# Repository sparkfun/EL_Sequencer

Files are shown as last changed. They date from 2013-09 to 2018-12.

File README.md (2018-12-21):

EL Sequencer
============

[EL Sequencer  
*EL Sequencer (COM-11323)*](https://www.sparkfun.com/products/11323)

The EL Sequencer is a board that contains an Arduino-compatible microcontroller, 
and circuitry for controlling up to eight strands of electroluminescent wire.

Repository Contents
-------------------
* **/Firmware** - Example Arduino sketches
* **/Hardware** - All Eagle design files (.brd, .sch)

Documentation
--------------
* **[Getting Started with Electroluminescent (EL) Wire](https://learn.sparkfun.com/tutorials/getting-started-with--el-wire)** - Basic tutorial on EL Wire
* **[Hookup Guide](https://learn.sparkfun.com/tutorials/el-sequencerescudo-dos-hookup-guide)** - Basic hookup guide for the EL Sequencer

License Information
-------------------
The hardware is released under [Creative Commons Share-alike 3.0](http://creativecommons.org/licenses/by-sa/3.0/).  
All other code is open source so please feel free to do anything you want with it; 
you buy me a beer if you use this and we meet someday ([Beerware license](http://en.wikipedia.org/wiki/Beerware)).

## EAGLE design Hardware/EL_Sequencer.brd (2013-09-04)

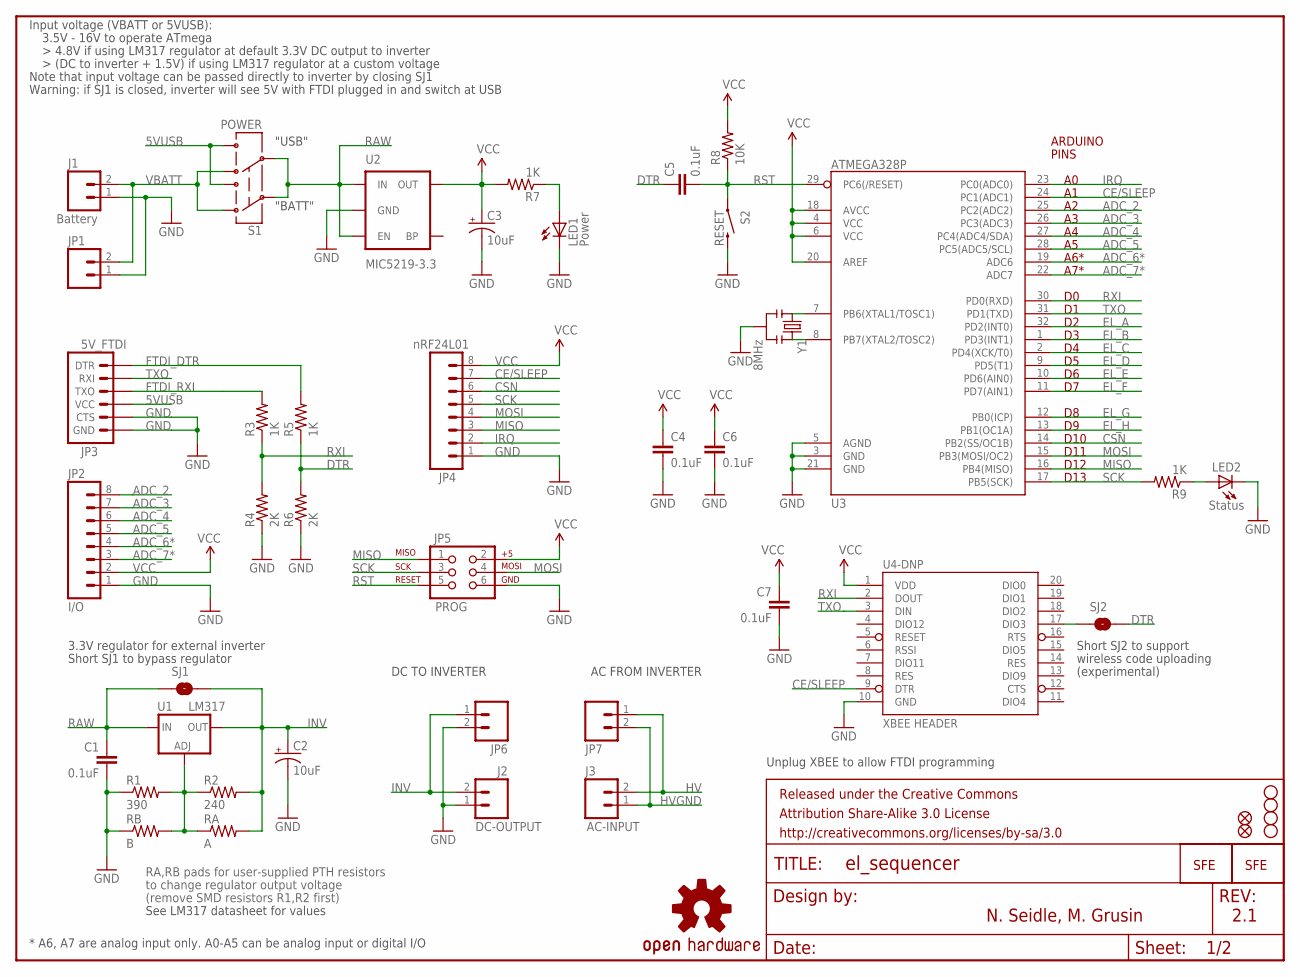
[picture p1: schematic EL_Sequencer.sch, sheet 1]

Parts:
C1, C4, C5, C6, C7: 0.1uF; 0402-CAP
C2, C3: 10uF; EIA3216
FRAME1: FRAME-LETTER; CREATIVE_COMMONS
J1: Battery; JST-2-SMD
J2: DC-OUTPUT; JST-2-SMD
J3: AC-INPUT; JST-2-SMD
JP1, JP6, JP7: M02PTH; 1X02
JP2: I/O; 1X08_ROUND
JP3: 5V_FTDI; 1X06
JP4: nRF24L01; 1X08
JP5: PROG; 2X3
JP8: LOGO-SFESK; SFE-LOGO-FLAME
LED1: Power; LED-0603
LED2: Status; LED-0603
R1: 390; 0603-RES
R2: 240; 0603-RES
R3, R5, R7, R9: 1K; 0402-RES
R4, R6: 2K; 0402-RES
R8: 10K; 0402-RES
RA: A; AXIAL-0.4
RB: B; AXIAL-0.4
S1: POWER; AYZ0202
S2: RESET; TACTILE_SWITCH_SMD
SJ1: SOLDERJUMPERROUND; SJ_ROUND
SJ2: SOLDERJUMPERNO; SJ_2S-NO
U1: LM317; V-REG_DPACK
U2: MIC5219-3.3; SOT23-5
U3: ATMEGA328P; TQFP32-08
U4-DNP: XBEE HEADER; XBEE-LONGPAD
U$1: OSHW-LOGOS; OSHW-LOGO-S
U$2: LOGO-SFENEW; SFE-NEW-WEBLOGO
U$3, U$4: FIDUCIALUFIDUCIAL; MICRO-FIDUCIAL
U$5, U$6, U$7, U$8: STAND-OFF
Y1: 8MHz; RESONATOR-SMD

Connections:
5VUSB: JP3.4 (VCC), S1.3, S1.6
ADC_2: JP2.8, U3.25 (PC2(ADC2))
ADC_3: JP2.7, U3.26 (PC3(ADC3))
ADC_4: JP2.6, U3.27 (PC4(ADC4/SDA))
ADC_5: JP2.5, U3.28 (PC5(ADC5/SCL))
ADC_6*: JP2.4, U3.19 (ADC6)
ADC_7*: JP2.3, U3.22 (ADC7)
CE/SLEEP: JP4.7, U3.24 (PC1(ADC1)), U4-DNP.9 (DTR)
CSN: JP4.6, U3.14 (PB2(SS/OC1B))
DTR: C5.1, R5.1, R6.2, SJ2.2
EL_A: U3.32 (PD2(INT0)); also elsewhere on the board
EL_B: U3.1 (PD3(INT1)); also elsewhere on the board
EL_C: U3.2 (PD4(XCK/T0)); also elsewhere on the board
EL_D: U3.9 (PD5(T1)); also elsewhere on the board
EL_E: U3.10 (PD6(AIN0)); also elsewhere on the board
EL_F: U3.11 (PD7(AIN1)); also elsewhere on the board
EL_G: U3.12 (PB0(ICP)); also elsewhere on the board
EL_H: U3.13 (PB1(OC1A)); also elsewhere on the board
FTDI_DTR: JP3.1 (DTR), R5.2
FTDI_RXI: JP3.3 (TXO), R3.2
GND: C1.2, C2.C (-), C3.C (-), C4.2, C6.2, C7.2, J1.1, J2.1, JP1.1, JP2.1, JP3.5 (CTS), JP3.6 (GND), JP4.1, JP5.6, JP6.2, LED1.C, LED2.C, R1.1, R4.1, R6.1, RB.P$1 (1), S2.3 (2), U2.2 (GND), U3.3 (GND), U3.5 (AGND), U3.21 (GND), U4-DNP.10 (GND), Y1.2; also elsewhere on the board
HV: J3.2, JP7.1; also elsewhere on the board
HVGND: J3.1, JP7.2; also elsewhere on the board
INV: C2.A (+), J2.2, JP6.1, R2.2, RA.P$2 (2), SJ1.2, U1.4 (OUT)
IRQ: JP4.2, U3.23 (PC0(ADC0))
MISO: JP4.3, JP5.1, U3.16 (PB4(MISO))
MOSI: JP4.4, JP5.4, U3.15 (PB3(MOSI/OC2))
unnamed: U3.7 (PB6(XTAL1/TOSC1)), Y1.1
unnamed: LED1.A, R7.1
unnamed: U3.8 (PB7(XTAL2/TOSC2)), Y1.3
unnamed: SJ2.1, U4-DNP.17 (DIO3)
unnamed: R1.2, R2.1, RA.P$1 (1), RB.P$2 (2), U1.1 (ADJ)
unnamed: LED2.A, R9.1
RAW: C1.1, S1.2, S1.5, SJ1.1, U1.3 (IN), U2.1 (IN), U2.3 (EN)
RST: C5.2, JP5.5, R8.1, S2.1, U3.29 (PC6(/RESET))
RXI: R3.1, R4.2, U3.30 (PD0(RXD)), U4-DNP.2 (DOUT)
SCK: JP4.5, JP5.3, R9.2, U3.17 (PB5(SCK))
TXO: JP3.2 (RXI), U3.31 (PD1(TXD)), U4-DNP.3 (DIN)
VBATT: J1.2, JP1.2, S1.1, S1.4
VCC: C3.A (+), C4.1, C6.1, C7.1, JP2.2, JP4.8, JP5.2, R7.2, R8.2, U2.5 (OUT), U3.4 (VCC), U3.6 (VCC), U3.18 (AVCC), U3.20 (AREF), U4-DNP.1 (VDD)

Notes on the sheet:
DC TO INVERTER
RA,RB pads for user-supplied PTH resistors
to change regulator output voltage
(remove SMD resistors R1,R2 first)
AC FROM INVERTER
A6*
A7*
D10
D11
D12
D13
N. Seidle, M. Grusin
2.1
Short SJ1 to bypass regulator
3.3V regulator for external inverter
Short SJ2 to support
wireless code uploading
* A6, A7 are analog input only. A0-A5 can be analog input or digital I/O
ARDUINO
PINS
See LM317 datasheet for values
(experimental)
3.5V - 16V to operate ATmega
Input voltage (VBATT or 5VUSB):
Note that input voltage can be passed directly to inverter by closing SJ1
Warning: if SJ1 is closed, inverter will see 5V with FTDI plugged in and switch at USB
"USB"
"BATT"
Unplug XBEE to allow FTDI programming

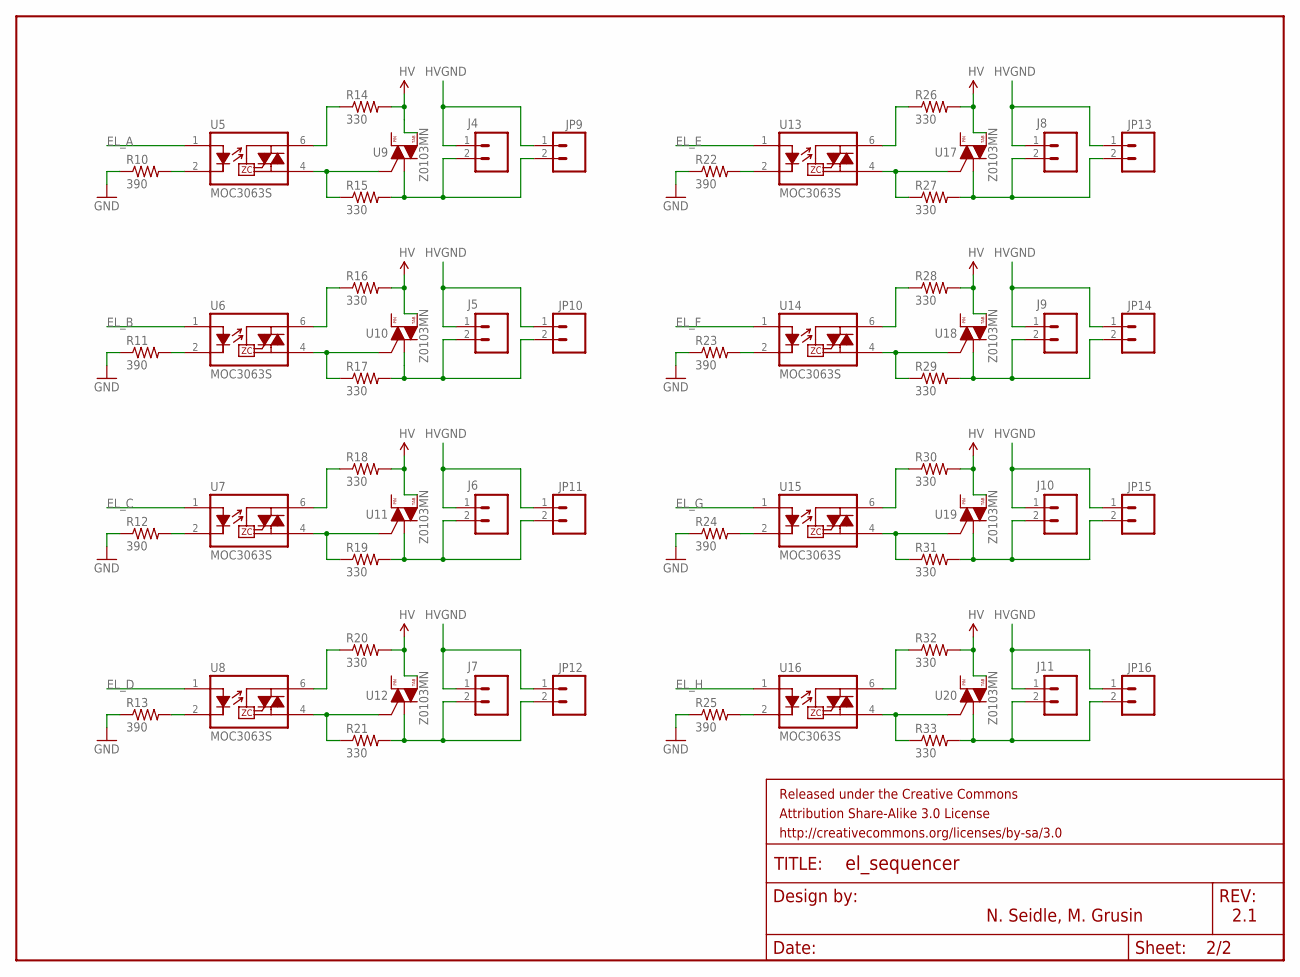
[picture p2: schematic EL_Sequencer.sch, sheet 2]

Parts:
FRAME2: FRAME-LETTER; CREATIVE_COMMONS
J4, J5, J6, J7, J8, J9, J10, J11: M02-JST-2MM-SMT; JST-2-SMD
JP9, JP10, JP11, JP12, JP13, JP14, JP15, JP16: M02PTH; 1X02
R10, R11, R12, R13, R22, R23, R24, R25: 390; 0402-RES
R14, R15, R16, R17, R18, R19, R20, R21, R26, R27, R28, R29, R30, R31, R32, R33: 330; 0603-RES
U5, U6, U7, U8, U13, U14, U15, U16: MOC3063S; DIP8SMD
U9, U10, U11, U12, U17, U18, U19, U20: Z0103MN; SOT223

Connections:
EL_A: U5.1 (A); also elsewhere on the board
EL_B: U6.1 (A); also elsewhere on the board
EL_C: U7.1 (A); also elsewhere on the board
EL_D: U8.1 (A); also elsewhere on the board
EL_E: U13.1 (A); also elsewhere on the board
EL_F: U14.1 (A); also elsewhere on the board
EL_G: U15.1 (A); also elsewhere on the board
EL_H: U16.1 (A); also elsewhere on the board
GND: R10.1, R11.1, R12.1, R13.1, R22.1, R23.1, R24.1, R25.1; also elsewhere on the board
HV: R14.2, R16.2, R18.2, R20.2, R26.2, R28.2, R30.2, R32.2, U9.4 (T2), U10.4 (T2), U11.4 (T2), U12.4 (T2), U17.4 (T2), U18.4 (T2), U19.4 (T2), U20.4 (T2); also elsewhere on the board
HVGND: J4.1, J5.1, J6.1, J7.1, J8.1, J9.1, J10.1, J11.1, JP9.1, JP10.1, JP11.1, JP12.1, JP13.1, JP14.1, JP15.1, JP16.1; also elsewhere on the board
unnamed: R17.1, U6.4 (T2), U10.3 (G)
unnamed: R11.2, U6.2 (K)
unnamed: R16.1, U6.6 (T1)
unnamed: R10.2, U5.2 (K)
unnamed: J5.2, JP10.2, R17.2, U10.1 (T1)
unnamed: R19.1, U7.4 (T2), U11.3 (G)
unnamed: R14.1, U5.6 (T1)
unnamed: R12.2, U7.2 (K)
unnamed: R18.1, U7.6 (T1)
unnamed: J6.2, JP11.2, R19.2, U11.1 (T1)
unnamed: R21.1, U8.4 (T2), U12.3 (G)
unnamed: R13.2, U8.2 (K)
unnamed: R20.1, U8.6 (T1)
unnamed: J7.2, JP12.2, R21.2, U12.1 (T1)
unnamed: J4.2, JP9.2, R15.2, U9.1 (T1)
unnamed: R27.1, U13.4 (T2), U17.3 (G)
unnamed: R22.2, U13.2 (K)
unnamed: R26.1, U13.6 (T1)
unnamed: J8.2, JP13.2, R27.2, U17.1 (T1)
unnamed: R29.1, U14.4 (T2), U18.3 (G)
unnamed: R23.2, U14.2 (K)
unnamed: R28.1, U14.6 (T1)
unnamed: J9.2, JP14.2, R29.2, U18.1 (T1)
unnamed: R31.1, U15.4 (T2), U19.3 (G)
unnamed: R24.2, U15.2 (K)
unnamed: R30.1, U15.6 (T1)
unnamed: J10.2, JP15.2, R31.2, U19.1 (T1)
unnamed: R33.1, U16.4 (T2), U20.3 (G)
unnamed: R25.2, U16.2 (K)
unnamed: R32.1, U16.6 (T1)
unnamed: J11.2, JP16.2, R33.2, U20.1 (T1)
unnamed: R15.1, U5.4 (T2), U9.3 (G)

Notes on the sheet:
N. Seidle, M. Grusin
2.1

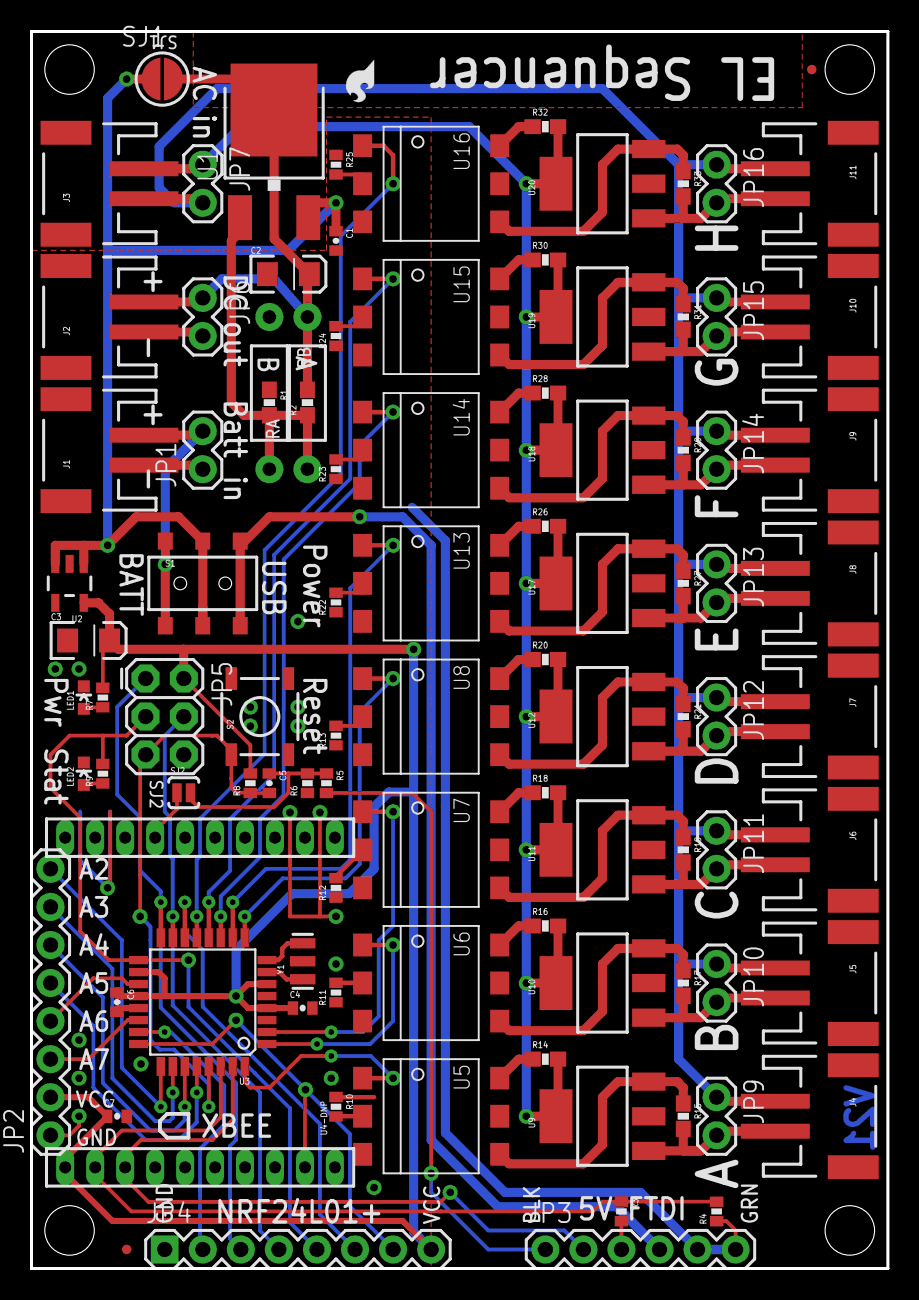
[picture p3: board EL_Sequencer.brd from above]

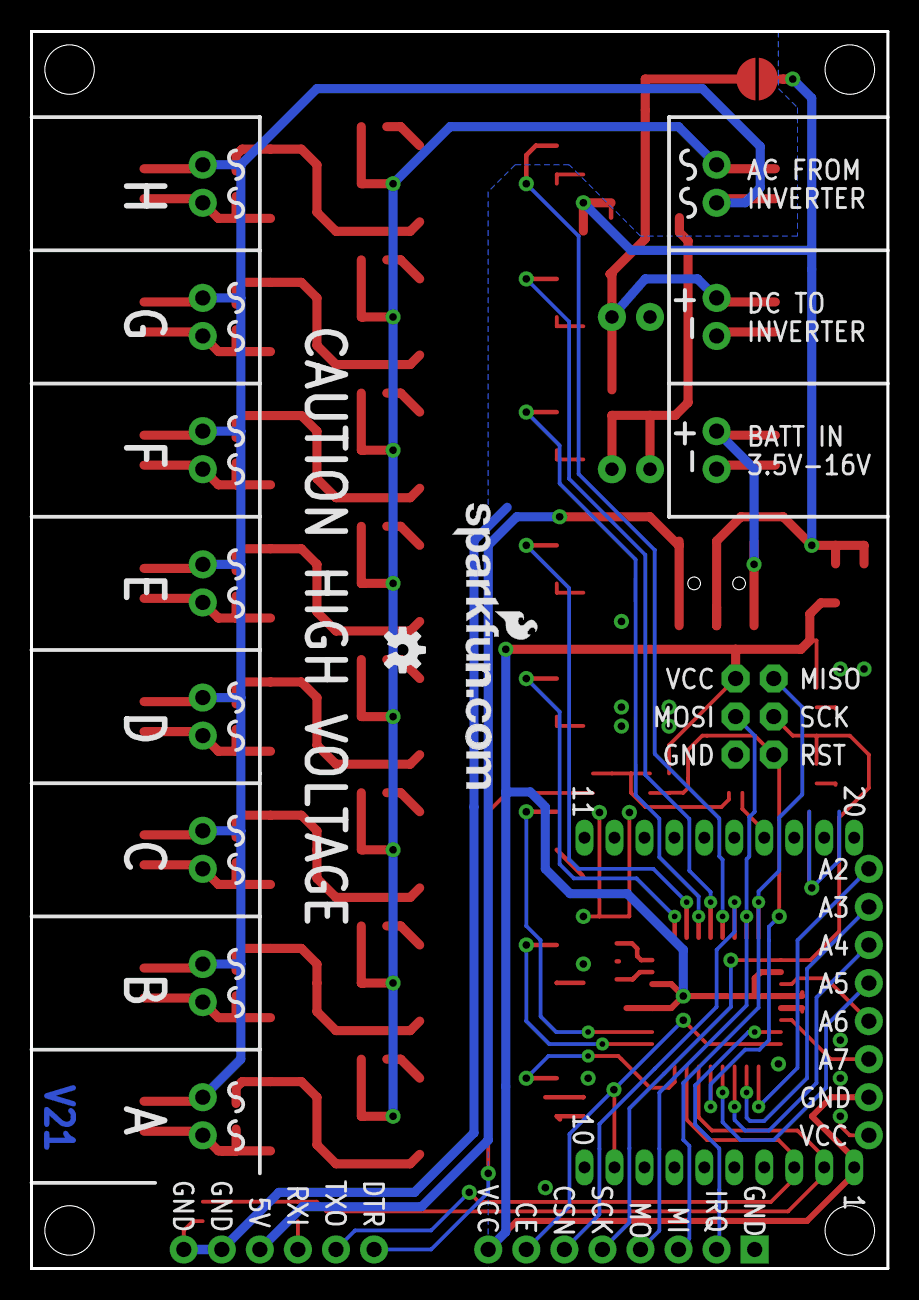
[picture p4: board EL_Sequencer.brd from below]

Board: 2 copper layers, 57.1 x 82.5 mm, 106 parts (2 on the bottom side), 72 nets.

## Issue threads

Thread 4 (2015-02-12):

Board issues found reviewing for reds

lewispg228, 2015-02-12:
1) ATmega328 needs to be updated to the new package that has the polarity dot outside the package

2) "-Mgrusin" text object is chillin on the tvalues layer.

mgrusin, 2015-02-12:
It's what we do.

ToniCorinne, 2015-02-12:
Both fixed!

Closed 2015-02-12.

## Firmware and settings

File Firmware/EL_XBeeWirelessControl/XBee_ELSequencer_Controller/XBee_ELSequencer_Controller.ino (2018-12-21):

/*
Remote Push Button Controller for EL Sequencer w/ XBee Series 1
Ho Yun Bobby Chan @ SparkFun Electronics
June 20, 2014

Description:
This is a basic test of the EL Sequencer with a wireless controller.
The wireless controller consists of an Arduino Uno, XBee Explorer,
XBee Series 1 transceiver, and LED Push Button. The EL Sequencer
uses an EL component, EL inverter, XBee female sockets soldered,
battery, and a XBee Series 1 transceiver. An XBee Series 2
can be used but the throughput of the Series 1 is much higher. To
reduce latency, I recommend using the XBee Series 1. The basic
configuration of the XBee module with point-to-point configuratin is
based on Digi's Example tutorial for "Basic XBee 802.15.4 (Series 1) Chat"
=> https://www.digi.com/blog/xbee/basic-xbee-802-15-4-chat/ .
Page 5 of the tutorial shows you how to broadcast with
point-to-multipoint configuration so that multiple EL Sequencers
can be controlled.

Connect the XBee Explorer to the Arduino:
     GND = GND
     3.3V = 3.3V
     DOUT (i.e. Tx of XBee) = Pin 2 (Rx on Arduino)
     DIN (i.e. Rx of XBee)= Pin 3 (Tx on Arduino)

By pushing the button, a character is sent from a remote microcontroller.
The corresponding EL Sequencer will receive the character and control
the EL component on a channel that is associated with that character.
A LED push button was used but not necessary for this to operate. A
normal momentary push button can be used.

Connect momentary LED tactile push buttons to Arduino:
     C = pin 13, the cathode (+) of the LED
     A = GND, the anode (-) of the LED
     B1 = GND
     B2 = pin 8
     
Using an Arduino Uno, the XBee transceiver is connected to the 
Software Serial pins. By pushing the button, the Arduino will
send one character through the XBee. Logic is used to control
how many characters are sent with the push button. The Arduino
will not send another character until the button is pressed again.

NOte: This section of the code can be optimized. As the user is not 
pressing down on the button, logic can be added so that the XBee is
not continuously sending serial characters to the receiving 
EL Sequencer when idle.
*/

#include <SoftwareSerial.h>
SoftwareSerial xbee(2,3); //Rx = 2, Tx = 3

const int button1Pin = 8; //push button
const int ledPin1 = 13;  //LED on the push button

boolean prev_button1State = false;
boolean current_button1State = false;

void setup(){
  pinMode(button1Pin,INPUT_PULLUP); //use internal pullup resistor with LED

  pinMode (ledPin1, OUTPUT);
  Serial.begin(9600);
  Serial.println("Arduino started sending bytes via XBee");

  xbee.begin(9600);
  Serial.println("EL Sequencer Controller's XBee Ready to Communicate");
}

void loop(){
  int button1State;

  button1State = digitalRead(button1Pin);
  /*button1state
   - LOW or 0 means pressed
   - HIGH or 1 means not pressed
   */

  //if button is pressed, it will be pulled low
  if(button1State == LOW){
    digitalWrite(ledPin1, HIGH); //turn push button LED ON
    current_button1State = true; // button has been pressed once
    
    if(prev_button1State != current_button1State)//check to see if button is still being pressed
    {   
      Serial.println("Button is pressed.");
      xbee.write("A");//Tell Sequencer to change to mode
    }
    else{
      //do nothing because finger is still on button
    }
    prev_button1State = current_button1State;
  }

  //button has not been pressed, it will be high again
  else{
    current_button1State = false;
    digitalWrite(ledPin1, LOW); // turn push button LED OFF
    xbee.write("Z"); 
    
    prev_button1State = current_button1State;
  }

}

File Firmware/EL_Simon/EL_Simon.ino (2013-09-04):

/*
EL SimÃ³n
N.Poole 2011
SparkFun Electronics

I wrote this code just to show off some EL Panel. It originally ran on an EL Sequencer 
Board which had the Arduino Bootloader on it, but feel free to modify it for whatever
hardware you want! The hardware setup is pretty straight-forward: 4 EL Panels are connected
to the A,B,C and D outputs on the Sequencer and 4 Force Sensitive Resistors are mounted 
below them, attached to Analog pins A3-6. Finally, a buzzer or small speaker is connected
between A2 and ground. 

I could have just modified the Simon Game code from our small Simon games but I had always
wanted to write Simon as a programming exercise so this was my quick attempt. I hope you
find it helpful, and enjoy!


*/

int A = 0; //button A status
int B = 0; //button B status
int C = 0; //button C status
int D = 0; //button D status

int steps = 1; // # of steps

char Str1[20]; // This is where the correct answers will go

void setup() {
  
  Serial.begin(9600);
  
  Serial.println("Setup");
  
  pinMode(2, OUTPUT); // EL Panels
  pinMode(3, OUTPUT);
  pinMode(4, OUTPUT);
  pinMode(5, OUTPUT);
  
  pinMode(A6, INPUT); // FSRs
  pinMode(A3, INPUT);
  pinMode(A4, INPUT);
  pinMode(A5, INPUT);
  
  pinMode(A2, OUTPUT); // Buzzer
  
  randomSeed(analogRead(A7)); // floating analog pin
  
  for(int r = 0; r < 20; r++){ // fill our answer sheet with random steps
    Str1[r] = random(1,5);}

}

void loop() {
  
  Serial.println("Main Loop");
  
  if(steps > 19){winner();} // FTW
  
  simon(); //play (steps) number of steps
  
  player(); //get and check (steps) number of steps
  
  steps++; //add another step
    
}

void player(){
  
  Serial.println("Player LooP");
  
  int answer = 0; //guess for each step
  
  int input = 0; // # of steps you've made it through
  
  int poscheck = 0; //position of array to check
  
  int correct = 1; //correct guess flag
  
  while(input < steps && correct == 1){ //do until you're out of steps or until you get one wrong
    
  A = analogRead(A4);
  B = analogRead(A3);
  C = analogRead(A5);
  D = analogRead(A6);
  
  answer = 5; //decoy: if this changes, a button has been pressed
  
  if(A > 300){
  digitalWrite(2, HIGH);
  tone(A2, 440);
  input++;
  answer = 1;
  delay(1000);
  digitalWrite(2, LOW);
  noTone(A2);}

  if(B > 300){
  digitalWrite(3, HIGH);
  tone(A2, 500);
  input++;
  answer = 2;
  delay(1000);
  digitalWrite(3, LOW);
  noTone(A2);}

  if(C > 300){
  digitalWrite(4, HIGH);
  tone(A2, 540);
  input++;
  answer = 3;
  delay(1000);
  digitalWrite(4, LOW);
  noTone(A2);}

  if(D > 300){
  digitalWrite(5, HIGH);
  tone(A2, 600);
  input++;
  answer = 4;
  delay(1000);
  digitalWrite(5, LOW);
  noTone(A2);}
  
  if(answer != 5){ //if a button was pressed
  
  poscheck = input - 1; //check position of array equal to # of inputs - 1 because arrays start at 0
  
  if(answer != Str1[poscheck]){correct = 0;} //if it's wrong, mark it wrong
  }

if(correct == 0){loser();} //if you were booted from the loop for a wrong answer, end the game

} } 

void simon(){
  
  Serial.println("simon loop");
  
    for(int s = 0; s < steps; s++){ //play each step for the player
    
    int currentstep = Str1[s];
    
    if(currentstep == 1){
  digitalWrite(2, HIGH);
  tone(A2, 440);
  delay(1000);
  digitalWrite(2, LOW);
  noTone(A2);}
              
    if(currentstep == 2){
  digitalWrite(3, HIGH);
  tone(A2, 500);
  delay(1000);
  digitalWrite(3, LOW);
  noTone(A2);}
      
        
    if(currentstep == 3){
  digitalWrite(4, HIGH);
  tone(A2, 540);
  delay(1000);
  digitalWrite(4, LOW);
  noTone(A2);}
        
    if(currentstep == 4){
  digitalWrite(5, HIGH);
  tone(A2, 600);
  delay(1000);
  digitalWrite(5, LOW);
  noTone(A2);}
    }
    
}

void loser(){ //if you're here... you lost.

Serial.println("loser loop");
  
  for(int b = 0;b < 5;b++){ //flash and beep alot, make them hate themselves for losing
  
  digitalWrite(2, HIGH);
  digitalWrite(3, HIGH);
  digitalWrite(4, HIGH);
  digitalWrite(5, HIGH);
  tone(A2, 200);
  
  delay(500);
  
  digitalWrite(2, LOW);
  digitalWrite(3, LOW);
  digitalWrite(4, LOW);
  digitalWrite(5, LOW);
  noTone(A2);
  
  delay(500);}

steps = 1; //reset global variable

setup(); //start all over

}

void winner(){ //congrats!
  
  Serial.print("sheen loop");
  
  for(int l = 0; l < 10; l++){ //cycle lights, celebrate
      digitalWrite(2, HIGH);
      delay(100);
      digitalWrite(2,LOW);
      digitalWrite(3, HIGH);
      delay(100);
      digitalWrite(3,LOW);
      digitalWrite(4, HIGH);
      delay(100);
      digitalWrite(4,LOW);
      digitalWrite(5, HIGH);
      delay(100);
      digitalWrite(5,LOW);}
      
   for(int n = 0; n < 20; n++){tone(A2, (300+(n*2)));} //play 'em up
   for(int n = 20; n > 0; n--){tone(A2, (300+(n*2)));} //play 'em down
   noTone(A2);
   
  steps = 1; //reset global variable

  setup(); //start all over
 
}
   
  

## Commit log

2013-09-04 Initial repo commit
    [EL_Sequencer.brd, EL_Sequencer.sch]
2013-09-04 Update README.md
    Added basic board description.
2015-01-25 Adding Code for Wireless Control of EL Sequencer
    Adding example sketch code to wirelessly control EL Sequencer w/ a
    remote Arduino to control the channels. Using XBee Series 1.

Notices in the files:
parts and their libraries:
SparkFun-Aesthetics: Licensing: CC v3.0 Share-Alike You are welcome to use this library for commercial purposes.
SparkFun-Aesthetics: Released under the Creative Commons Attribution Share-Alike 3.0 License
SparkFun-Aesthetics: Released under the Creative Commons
